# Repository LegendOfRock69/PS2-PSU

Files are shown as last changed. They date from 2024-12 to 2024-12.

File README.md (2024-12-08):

## PS2-PSU
The PS2-PSU is a custom regulator solution meant for powering Playstation 2 Slims that have had an Advanced Trim performed to them or untrimmed consoles with the existing power regulatory components removed.

3DViewer
PCBNew

## Disclaimer
This is **NOT** a "drop-in" power regulator solution for portable PS2's. This board is meant to **only** be powered externally via USB-C and should not be powered by a battery. It is meant to power PS2's that have been trimmed and require the [Advanced Trim voltage relocations](https://bitbuilt.net/forums/index.php?threads/the-definitive-ps2-trimming-guide.1841/); or PS2's that have had their existing power regulating components removed. This board has only been tested with a SCPH-79001 motherboard so far but should work with any SCPH-7900X PS2 Slim; or any Playstation 2 Slim that requires the necessary voltages. Revision 2 is planned to be a full "drop-in" solution to use for portables in conjunction with a separate battery protection PCB and will be released soon.

This board has **only** been tested with the [Adafuit 5803](https://www.mouser.ca/ProductDetail/Adafruit/5803?qs=QpmGXVUTftHXtVI1Nl%252BHoQ%3D%3D) 5V 4A output wall adapter outlined in the BOM but any USB-C charger should work as long as it can output at least 3A or more. It is also **strongly** recommended to only use 5V to power this board as the main TPS62A06DRLR regulators have a maximum input voltage rating of 5.5v and anything higher can and will have the potential to damage the components.

## Features
- Board Dimentions: 61mm x 25mm
- Powered via USB-C
- Uses more standard voltages and 1 less regulator as opposed to the voltages recommended in the PS2 Trimming Guide

## Gallery
BoardTopBoardBottomWiredTopBoot

## Order & Assembly
- The gerber files can be uploaded to any PCB manufacturer of your choice for ordering
- While it is recommended to order this board with an ENIG surface finish, a HASL(with lead) finish will work as well
- It is **strongly** recommended to order a stencil for assembly and it is not recommended to hand solder the components
- There are 3 BOM file types included: a .xlsx BOM, a .pdf BOM and an iBOM.html
- The Bill of Materials for this board were ordered from Mouser however components can be ordered from the supplier of your choice so long as they are stocked. links to a supplier were left out in the BOM for users who may prefer a different supplier
- As per the disclaimer, the Adafruit 5803 outlined in the BOM is recommended for not only its voltage and amperage output, but it also has an external switch to utilize as the board will be powered once plugged in if not using an external switch

## Installation
Whereas the PS2-PSU uses more standard voltages than the those outlined in the [Definitive PS2 Trimming Guide](https://bitbuilt.net/forums/index.php?threads/the-definitive-ps2-trimming-guide.1841/), the connections are as follows:

- 1V on the PSU is required to be connected to the PS2's 1.25V area
- 1V8 on the PSU is required to be connected to **BOTH** the PS2's 1.75V **and** 2.5V areas
- 3V3 on the PSU is required to be connected to the PS2's 3.5V area
- 5V on the PSU is required to be connected to the PS2's 5V area

**Please note that all volatge relocations MUST be connected together on a trimmed PS2 as trimming cuts away the internal voltage layers that connects them together**

SCPH-79001 and alike (please note that the 2 8-pin IC's circled in red must be removed if they are present) Voltage_79001

SCPH-79003 and alike Voltage_79003

When using this PSU or any custom regulator solution to externally power a PS2, 3.5V (or 3V3) must be reconnected to this area on the 8-pin ic. If the 8-pin ic is not present, 3.5v (or 3V3) must be connected to the small capacitor above it 

Voltage Relocation Back 79001_for PS2PMS

5V **must** be connected to the orange area in this photo as it powers both the DAC and the Ethernet IC and is a requirement for the PS2 to boot Video_Bottom

## License
[Solderpad Hardware License v2.1](https://solderpad.org/licenses/SHL-2.1/)

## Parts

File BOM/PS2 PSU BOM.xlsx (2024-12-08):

Item # | Reference Designator | Quantity | Manufacturer | Mfr. Part # | Description | Package | Type
1 | U1, U2, U3 | 3 | Texas Instruments | TPS62A06DRLR | Switching Voltage Regulators 2.5-V to 5.5-V input, 6-A high-efficiency step-down converter in SOT-563 package 6-SOT-5X3 -40 to 125 | SOT-563-6 | SMD/SMT
2 | U4 | 1 | Texas Instruments | TLV75718PDRVR | LDO Voltage Regulators 1-A, low-IQ high-accuracy low-dropout (LDO) voltage regulator with enable 6-WSON -40 to 125 | WSON-6 | SMD/SMT
3 | L1, L2 | 2 | Coilcraft | XAL4020-222MEC | Power Inductors - SMD 2.2uH Shld 20% 5.5A 38.7mOhms AECQ2 | 1616 (4040 metric) | SMD/SMT
4 | L3 | 1 | Coilcraft | XAL4020-102MEC | Power Inductors - SMD 1uH Shld 20% 9.6A 14.6mOhms AECQ2 | 1616 (4040 metric) | SMD/SMT
5 | C1 - C15, C17, C18 | 17 | Murata Electronics | GRM21BZ71A226ME15L | Multilayer Ceramic Capacitors MLCC - SMD/SMT 22 uF 10 VDC 20% 0805 X7R | 0805 (2012 metric) | SMD/SMT
6 | C16, C19 | 2 | Murata Electronics | GCM21BR71A106KE22L | Multilayer Ceramic Capacitors MLCC - SMD/SMT 10 uF 10 VDC 10% 0805 X7R AEC-Q200 | 0805 (2012 metric) | SMD/SMT
7 | R3, R6, R8 | 3 | YAGEO | RP0603BRD0710KL | Thin Film Resistors - SMD 1/10 Wa 10K Ohm 0.1% 0603 AEC-Q200 | 0603 (1608 metric) | SMD/SMT
8 | R1, R2 | 2 | YAGEO | RP0402BRD075K1L | Thin Film Resistors - SMD 1/16Wa 5.1K Ohm 0.1% 0402 AEC-Q200 | 0402 (1005 metric) | SMD/SMT
9 | R4 | 1 | YAGEO | RT0603BRD0773K2L | Thin Film Resistors - SMD 1/10W 73.2K ohm .1% 25ppm | 0603 (1608 metric) | SMD/SMT
10 | R5 | 1 | YAGEO | RT0603BRE0745K3L | Thin Film Resistors - SMD 45.3 kOhms 50PPM/C 100mW 0603 10% | 0603 (1608 metric) | SMD/SMT
11 | R7 | 1 | YAGEO | RT0603BRD076K8L | Thin Film Resistors - SMD 1/10W 6.8K ohm .1% 25ppm | 0603 (1608 metric) | SMD/SMT
12 | J1 | 1 | GCT | USB4125-GF-A | USB Connectors USB C Rec, GF, RA, 6p, SMT, TH stakes, H = 3.16mm, T+R | N/A | SMD/SMT
13 | N/A | 1 | Adafruit | 5803 | Wall Mount AC Adapters Wall Power Supply with USB C - 5V 4A Output and Switch | N/A | N/A

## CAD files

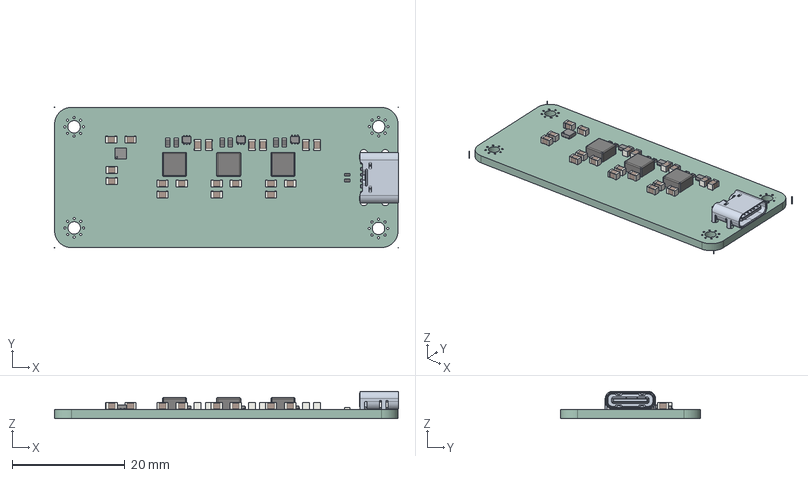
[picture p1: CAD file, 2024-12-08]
3D/PS2 PSU.step
61.1 x 24.9 x 4.88 mm
R_0402_1005Metric x 2
C_0805_2012Metric x 19
R_0603_1608Metric x 6
DRL6 x 3
CQ assembly x 3
DRV6
USB4125-GF-A
PS2 PSU_PCB_1
PS2 PSU_PCB_2
PS2 PSU_PCB_3
PS2 PSU_PCB_4
PS2 PSU_PCB_5

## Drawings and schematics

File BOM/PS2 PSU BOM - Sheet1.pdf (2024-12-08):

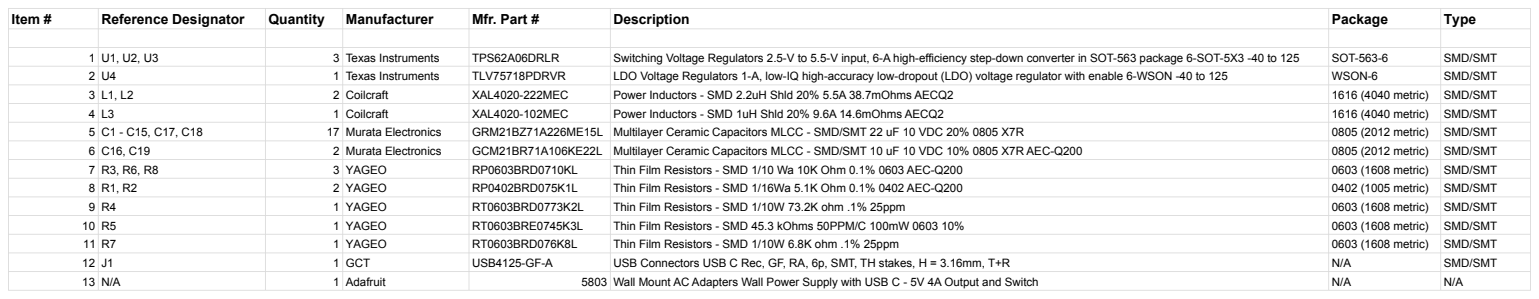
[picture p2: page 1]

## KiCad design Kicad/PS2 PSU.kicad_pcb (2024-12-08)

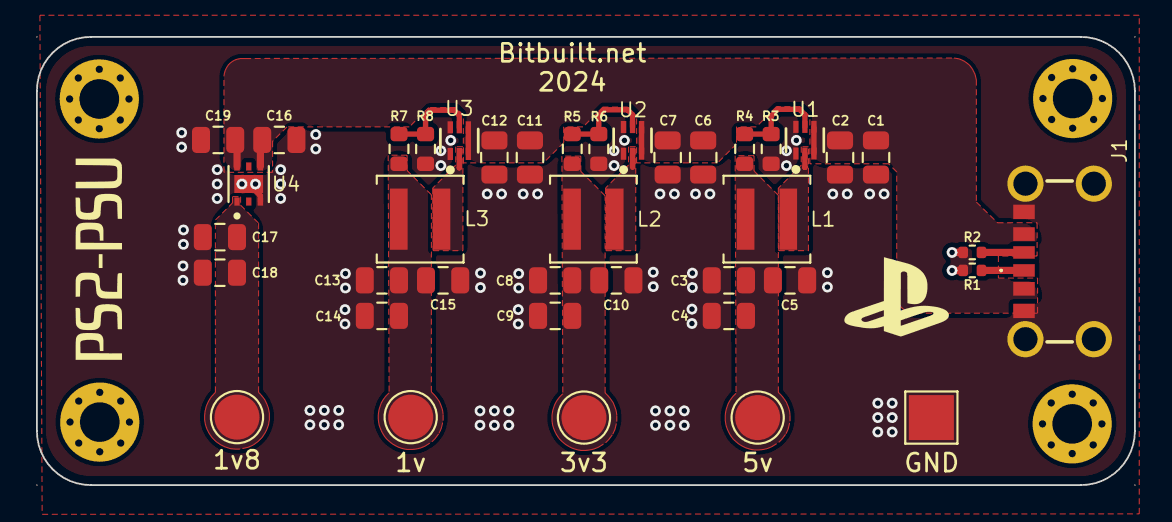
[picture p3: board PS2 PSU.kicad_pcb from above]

Board: 2 copper layers, 61.0 x 24.9 mm, 40 parts (0 on the bottom side), 14 nets.

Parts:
1v, 1v8, 3v3, 5v: TestPoint; TestPoint_Pad_D2.5mm
C1, C2, C3, C4, C5, C6, C7, C8, C9, C10, C11, C12, C13, C14, C15, C17, C18: 22uF; C_0805_2012Metric
C16, C19: 10uF; C_0805_2012Metric
GND: TestPoint; TestPoint_Pad_2.5x2.5mm
J1: USB4125-GF-A; USB4125GFA
L1, L2: 2.2uH; L_Coilcraft_XAL4020-XXX
L3: 1uH; L_Coilcraft_XAL4020-XXX
R1, R2: 5.1k; R_0402_1005Metric
R3, R6, R8: 10k; R_0603_1608Metric
R4: 73.2k; R_0603_1608Metric
R5: 45k; R_0603_1608Metric
R7: 6.8k; R_0603_1608Metric
U1, U2, U3: TPS62A06DRLR
U4: TLV75718PDRVR

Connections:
1v: 1v.1, C13.1, C14.1, C15.1, L3.2, R7.1
1v8: 1v8.1, C17.1, C18.1, U4.1 (OUT)
3v3: 3v3.1, C8.1, C9.1, C10.1, L2.2, R5.1
5v: 5v.1, C3.1, C4.1, C5.1, L1.2, R4.1
GND: C1.2, C2.2, C3.2, C4.2, C5.2, C6.2, C7.2, C8.2, C9.2, C10.2, C11.2, C12.2, C13.2, C14.2, C15.2, C16.2, C17.2, C18.2, C19.2, GND.1, J1.A12 (GND_1), J1.B12 (GND_2), J1.MH1, J1.MH2, J1.MH3, J1.MH4, R1.2, R2.2, R3.1, R6.1, R8.1, U1.1 (GND), U1.6 (PG), U2.1 (GND), U2.6 (PG), U3.1 (GND), U3.6 (PG), U4.3 (GND), U4.7 (EXP)
unnamed: J1.A5 (CC1), R1.1
unnamed: J1.B5 (CC2), R2.1
unnamed: R3.2, R4.2, U1.5 (FB)
unnamed: L1.1, U1.2 (SW)
unnamed: R5.2, R6.2, U2.5 (FB)
unnamed: L2.1, U2.2 (SW)
unnamed: R7.2, R8.2, U3.5 (FB)
unnamed: L3.1, U3.2 (SW)
VIN: C1.1, C2.1, C6.1, C7.1, C11.1, C12.1, C16.1, C19.1, J1.A9 (VBUS_1), J1.B9 (VBUS_2), U1.3 (VIN), U1.4 (EN), U2.3 (VIN), U2.4 (EN), U3.3 (VIN), U3.4 (EN), U4.4 (EN), U4.6 (IN)
